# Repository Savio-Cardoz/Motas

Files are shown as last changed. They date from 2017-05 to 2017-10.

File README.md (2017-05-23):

# Motas
Code for Motas controller with Ultrasonic, PIR and sd card implemented

Functions the abstraction layer can use.

To get the Time Count of Ultrasonic Sensor
  uint16_t Get_Uss_Count();    returns an integer with time count equivalent to distance
  
  uint16_t Get_Pir_Count();    returns an integer with the current count of PIR sensor triggers
  
  void Reset_Pir_Count();
  
  void Dfplayer_Cmd(uint8_t cmd, uint16_t parameter);   Takes command with parameter value for that command
  
  ***** Pending addition of 'reading status of DF player to enter debug mode *******

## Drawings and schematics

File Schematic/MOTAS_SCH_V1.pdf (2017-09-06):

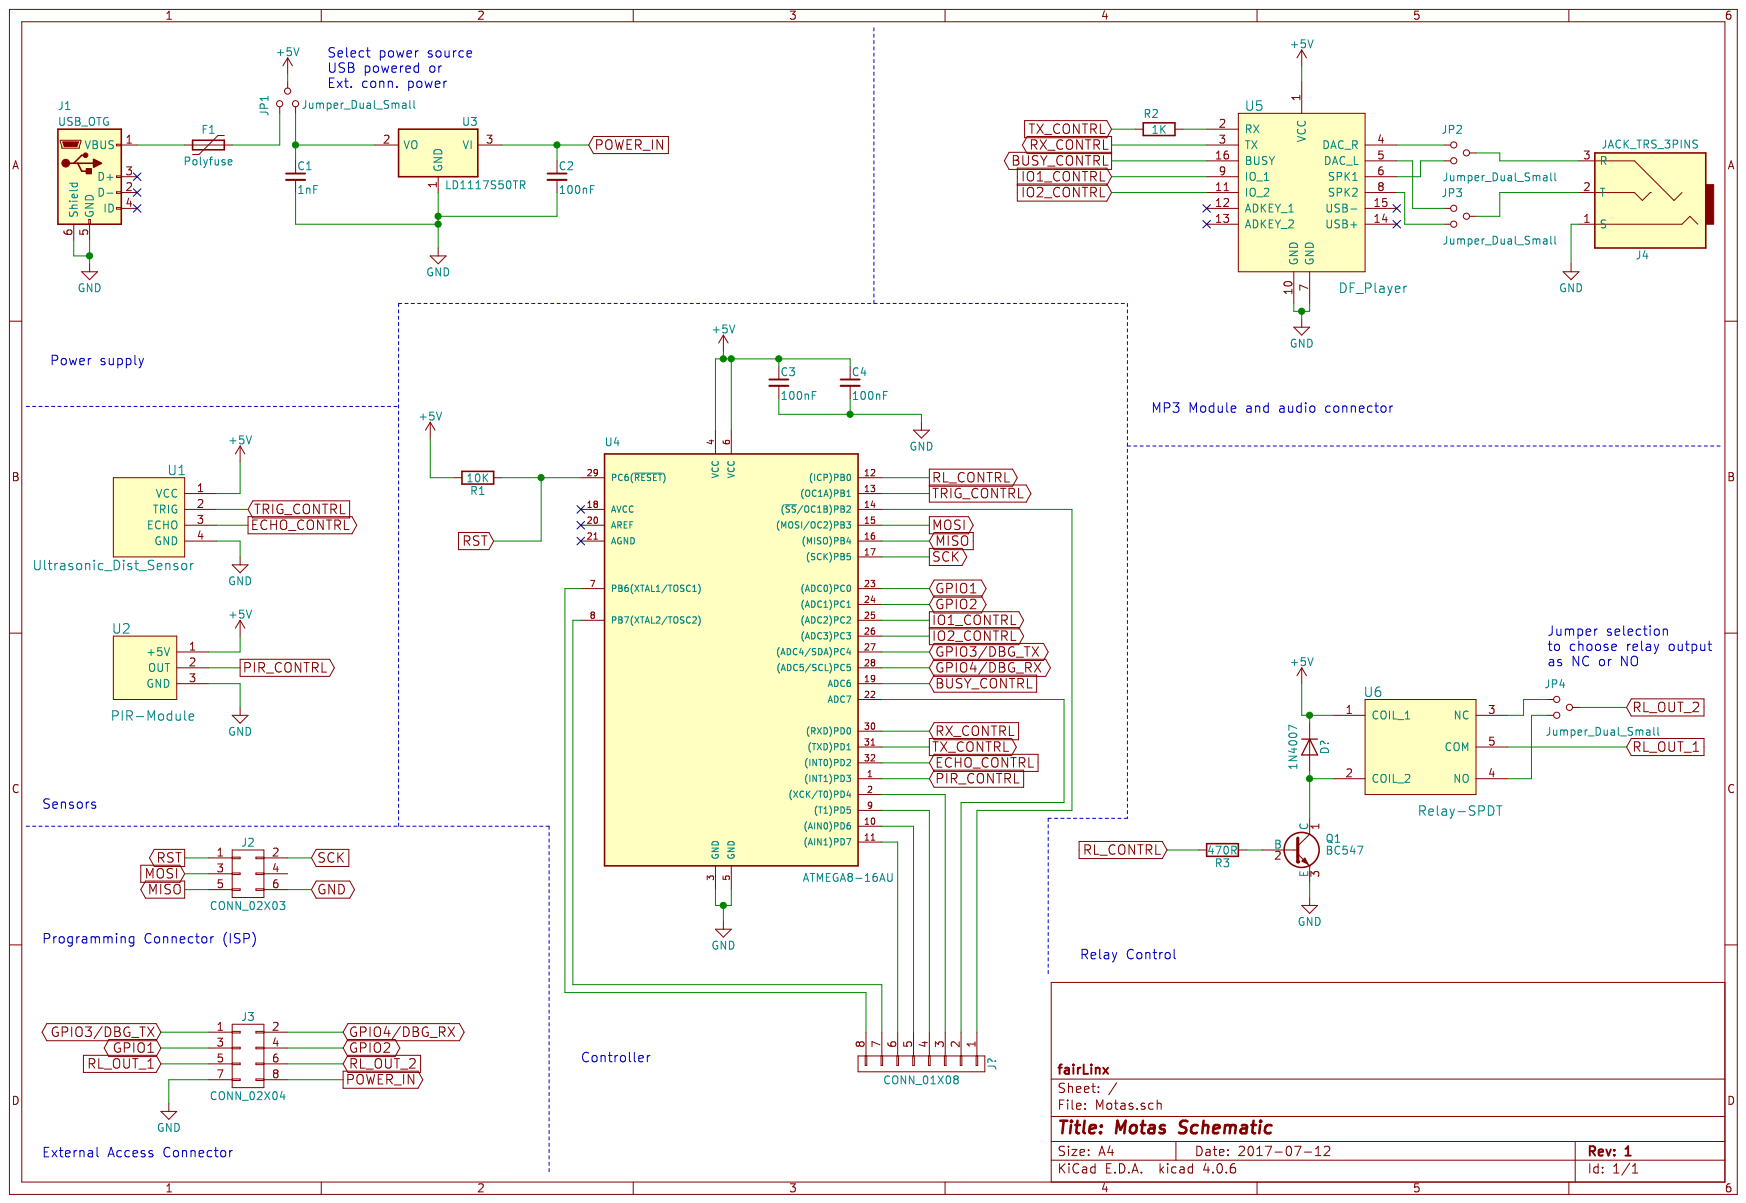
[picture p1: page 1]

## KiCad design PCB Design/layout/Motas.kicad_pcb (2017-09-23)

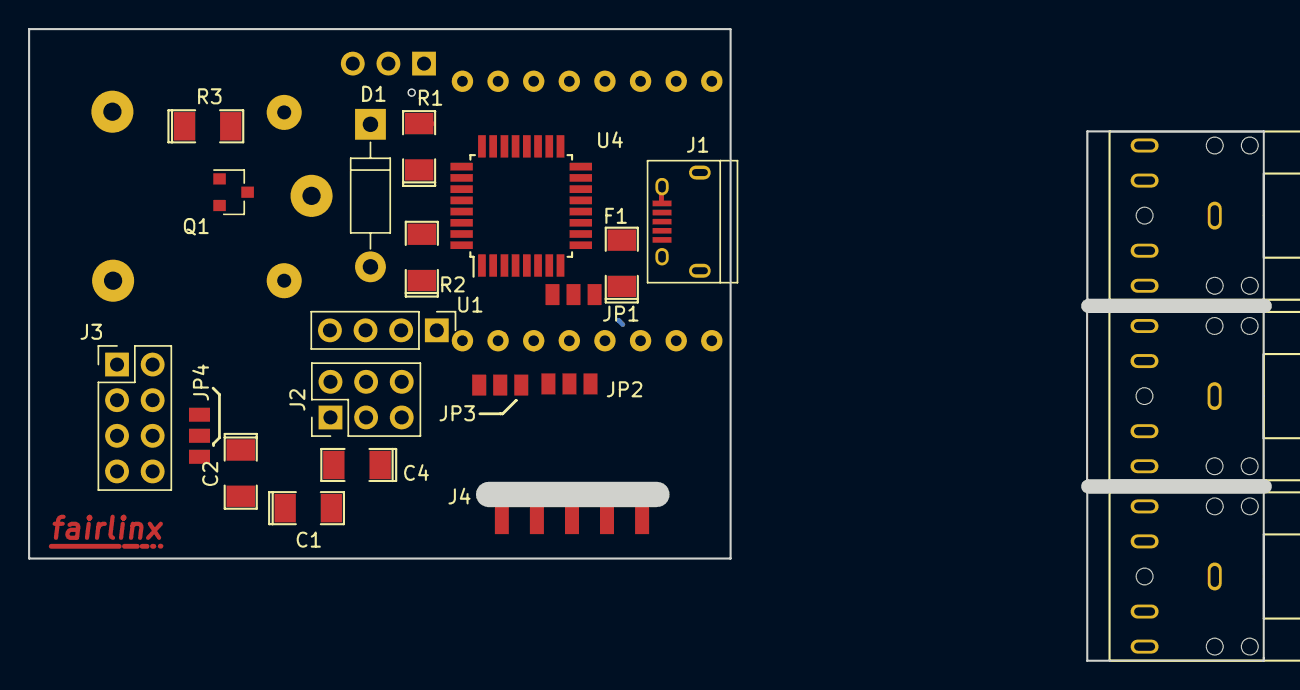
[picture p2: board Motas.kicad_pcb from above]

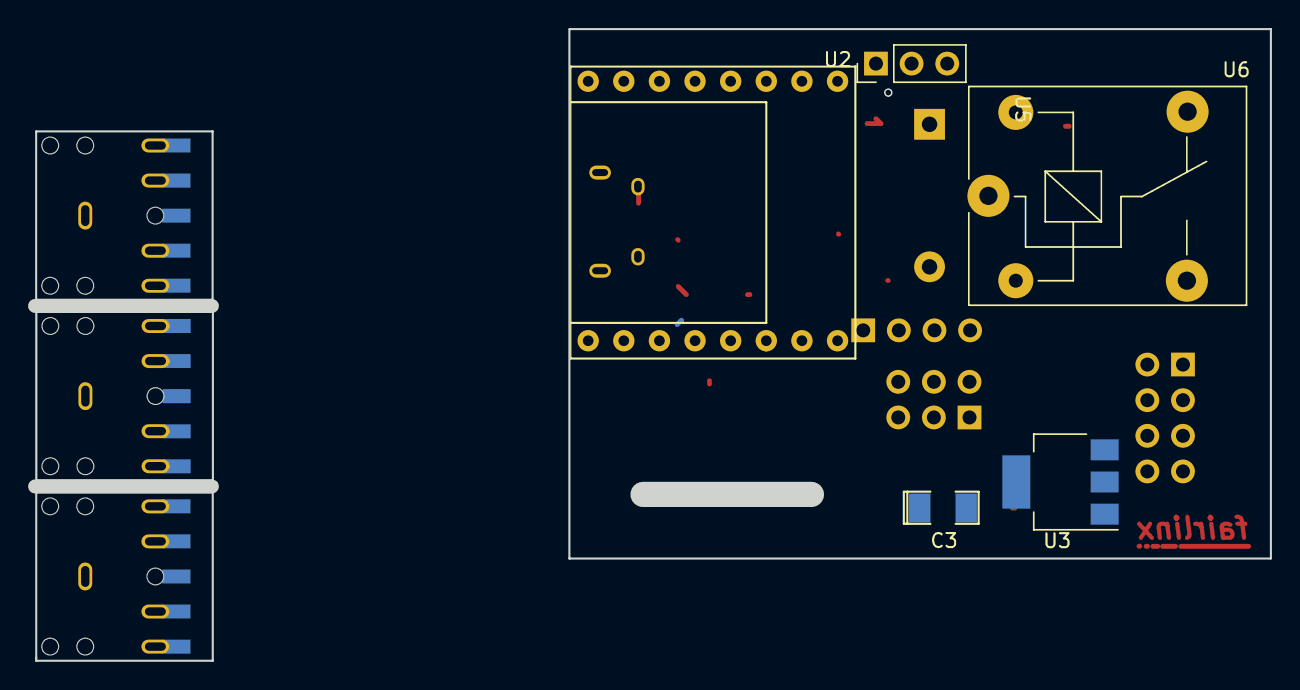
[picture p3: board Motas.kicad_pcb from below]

Board: 2 copper layers, 50.0 x 37.8 mm, 24 parts (5 on the bottom side), 36 nets.

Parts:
C1, C2, C3, C4: SMD-1206_Pol
D1: D_DO-41_SOD81_P10.16mm_Horizontal
F1: SMD-1206_Pol
J1: USB_Micro-B
J2: Pin_Header_Straight_2x03_Pitch2.54mm
J3: Pin_Header_Straight_2x04_Pitch2.54mm
J4: special_con_audio_socket_PCB
JP1, JP2, JP3, JP4: Jumper_3Pin_SMD
Q1: SOT-23
R1, R2, R3: SMD-1206_Pol
U1: Pin_Header_Straight_1x04_Pitch2.54mm
U2: Pin_Header_Straight_1x03_Pitch2.54mm
U3: SOT-223-3Lead_TabPin2
U4: TQFP-32_7x7mm_Pitch0.8mm
U5: DFPlayer
U6: Relay_SPDT_SANYOU_SRD_Series_Form_C

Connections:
+5V: C3.1, C4.1, D1.1, JP1.2, R1.2, U1.1, U2.1, U4.4, U4.6, U5.1, U6.5
BUSY_CONTRL: U4.19, U5.16
ECHO_CONTRL: U1.3, U4.32
GND: C1.2, C2.2, C3.2, C4.2, J1.5, J1.6, J2.6, J3.7, J4.1, Q1.2, U1.4, U2.3, U3.1, U4.3, U4.5, U5.7, U5.10
GPIO1: J3.3, U4.23
GPIO2: J3.4, U4.24
GPIO3/DBG_TX: J3.1, U4.27
GPIO4/DBG_RX: J3.2, U4.28
IO1_CONTRL: U4.25, U5.9
IO2_CONTRL: U4.26, U5.11
MISO: J2.5, U4.16
MOSI: J2.3, U4.15
unnamed: C1.1, JP1.3, U3.2
unnamed: D1.2, Q1.3, U6.2
unnamed: F1.1, JP1.1
unnamed: F1.2, J1.1
unnamed: J4.2, JP3.2
unnamed: J4.3, JP2.2
unnamed: JP2.1, U5.4
unnamed: JP2.3, U5.6
unnamed: JP3.1, U5.5
unnamed: JP3.3, U5.8
unnamed: JP4.1, U6.4
unnamed: JP4.3, U6.3
unnamed: Q1.1, R3.1
unnamed: R2.1, U5.2
PIR_CONTRL: U2.2, U4.1
POWER_IN: C2.1, J3.8, U3.3
RL_CONTRL: R3.2, U4.12
RL_OUT_1: J3.5, U6.1
RL_OUT_2: J3.6, JP4.2
RST: J2.1, R1.1, U4.29
RX_CONTRL: U4.30, U5.3
SCK: J2.2, U4.17
TRIG_CONTRL: U1.2, U4.13
TX_CONTRL: R2.2, U4.31

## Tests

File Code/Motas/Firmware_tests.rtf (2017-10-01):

1. Checked controller enters the main loop and loops through MotasController(); 26/09/2017
2. system state changes – POWER ON – MOTAS_INIT_STATE
void Init_State(void) → MOTAS_CALIBRATION_STATE
void Calibration_State(void) → Confusion here ???????????

3. Rectified code for swapped interrupt vectors to USS and PIR

4. Verified PIR being triggered as well as USS.
5. Systems goes through MOTAS_CALIBRATION_STATE . USS threshold set.
6. System enters MOTAS_STANDBY_STATE. USS and PIR values being monitored
7. scan rate seems to be slow. Maybe because debugging is active ____NEEDS TO BE VERIFIED

8. System enters MOTAS_ACTIVE_STATE. Cmd to play track sent.
9. USS needs to be auto triggered.

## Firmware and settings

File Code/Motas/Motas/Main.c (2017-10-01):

/*
 * MOTAS.c
 *
 * Created: 5/17/2017 10:53:48 PM
 *  Author: Cardoz
 */

 
/*
 *	Using the factory default internal RC oscillator
*/ 

#include <avr/io.h>
#include <util/delay.h>
#include <avr/interrupt.h>
#include "Atmega_Uart.h"
#include "Dfplayer.h"
#include "Peripheral_Drivers.h"
#include "Atmega_Config.h"
#include "Motas_Controller.h"
#include "debug_func.h"



int main(void)
{
	Atmega_init();
	
    while(1)
    {
		MotasController();
    }
}

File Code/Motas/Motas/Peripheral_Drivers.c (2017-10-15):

/*
 * peripheral_drivers.c
 *
 * Created: 5/17/2017 10:57:21 PM
 *  Author: Cardoz
 */ 
#include "Atmega_Config.h"
#include <avr/io.h>
#include <util/delay.h>
#include <avr/interrupt.h>
#include "Peripheral_Drivers.h"
#include "Motas_Controller.h"
#include "debug_func.h"
#include "Atmega_Uart.h"

static volatile uint16_t pir_trigger_count, UssPulseCount;
static volatile uint16_t timer1_ovf_count = 0;
extern uint8_t flag_register_controller;
extern uint16_t threshold_uss_count;

#define SET_USS_FLAG	({flag_register_controller |= (1 << 2);})
#define CLEAR_USS_FLAG  ({flag_register_controller &= ~(1 << 2);})

ISR(TIMER1_OVF_vect)
{
	++timer1_ovf_count;
}

ISR(TIMER0_OVF_vect)
{
	static uint16_t timer_ovf_count = 0;
	
	if((timer_ovf_count++) == 500)
	{
		Trigger_Ultrasonic_Sensor();
		timer_ovf_count = 0;
		TCCR0 &= ~(1 << CS00);		// Stop the timer. Timer is restarted in the USS echo received interrupt
		TCNT0 = 0;
	}
}

ISR(PIR_INTERRUPT_VECT)
{
	pir_trigger_count++;
}

ISR(USS_INTERRUPT_VECT)				
{
	static uint8_t UssEdgeCount = 0;
	if (UssEdgeCount)		
	{
		Stop_Timer1();
		UssPulseCount = TCNT1;		// Store the time duration of the echo pulse. 
		timer1_ovf_count = 0;
		TCNT1 = 0;
		UssEdgeCount = 0;
		MCUCR |= (1 << ISC01) | (1 << ISC00);												// Rising edge will trigger the next interrupt
		TCCR0 |= (1 << CS00);					// Start the timer0 to wait for 1ms to trigger the USS
		
		if(UssPulseCount < threshold_uss_count)
		{
			#if DEBUG_ON
			SendDebug("Thres_cross");
			USART_Transmit_dec(UssPulseCount);
			#endif	
			DebugLedTransmit(LED_ON, LED_RED);
			SET_USS_FLAG;	
		}
	}
	else 
	{
		Start_Timer1();
		UssEdgeCount = 1;
		MCUCR &= ~(1 << ISC00);										// falling edge for INT0 enabled
		MCUCR |= (1 << ISC01);
	}
}

void Trigger_Ultrasonic_Sensor()									// Function tested for 10us trigger 
{
	SETBIT(USS_TRIGGER_PORT, USS_TRIGGER_PIN);
	_delay_us(10);													// 10us Pulse as per datasheet of HC-SR04 Ultrasonic Sensor
	CLEARBIT(USS_TRIGGER_PORT, USS_TRIGGER_PIN);
}

void Init_Pir()
{
	CLEARBIT(PIR_INPUT_DIR_REG, PIR_INPUT_PIN);						// Set the pin direction as input
	SETBIT(PIR_INPUT_PORT, PIR_INPUT_PIN);							// Setup the controllers internal Pull up resistor

	MCUCR |= (1 << ISC11) | (1 << ISC10);
	GICR |= (1 << INT1);
}

void Init_Ultrasonic_Sensor()
{
	USS_TRIGGER_DIR_REG |= (1 << USS_TRIGGER_PIN);					// Set the pin direction as output
	USS_TRIGGER_PORT &= ~(1 << USS_TRIGGER_PIN);					// Initial state of trigger is LOW
	
	USS_ECHO_DIR_REG &= ~(1 << USS_ECHO_PIN);						// ECHO pin is set a s input
	USS_ECHO_PORT |= (1 << USS_ECHO_PIN);							// Keep ECHO pin pulled up
	
	/* Setup rising edge interrupt on the echo pin	*/	
	MCUCR |= (1 << ISC01) | (1 << ISC00);							// Set the interrupt to trigger at the rising edge.
	GICR |= (1 << INT0);
}

void Init_Led()
{
	SETBIT(DDRC, PC0);
	SETBIT(DDRC, PC1);
	CLEARBIT(PORTC, PC0);
	CLEARBIT(PORTC, PC1);	
}

void Led_On(uint8_t led_color)
{
	SETBIT(PORTC, led_color);
}

void Led_Off(uint8_t led_color)
{
	CLEARBIT(PORTC, led_color);
}

uint16_t Get_Uss_Count()
{
	// TODO: replace with a flag to check if the USS ECHO pulse has been received Speed can be 
	return UssPulseCount;
}


/* Timer 0 will be used to auto trigger the USS	@ periodic intervals	*/
void Init_Timer0()
{
	TIMSK |= (1 << TOIE0);
	TCCR0 |= (1 << CS00);		// Start the timer	default 256us overflow rate @ 1MHZ.
}

void Init_Timer1()
{
	TCNT1 = 0;
	TIMSK |= (1 << TOIE1);
}

void Start_Timer1()
{
	TCCR1B |= (1 << CS10);		// No pre-scalar
}

void Stop_Timer1()
{
	TCCR1B &= ~(1 << CS10);
}

uint16_t Get_Pir_count()
{
	#if DEBUG_ON
	SendDebug("PIR@");
	USART_Transmit_dec(pir_trigger_count);
	#endif
	return pir_trigger_count;
}

void Reset_Pir_count()
{
	pir_trigger_count = 0;
}

/*
 *	Return the digital level of the pin connected to the PIR output
 *	return 1 - if PIR is being triggered
 *	return 0 - No motion is detected by the PIR.
*/ 
uint8_t Get_Pir_status()
{
	if(CHECKBIT(PIND, PIR_INPUT_PIN))
	{
		#ifdef DEBUG_ON
		SendDebug("Motion active");
		#endif
		
		return 1;
	}
	#ifdef DEBUG_ON
	SendDebug("No Motion");
	#endif
	
	return 0;
}

void Init_Gpio()
{
	RELAY_PORT_DIR_REG |= (1 << RELAY_PIN);		// Set the relay pin as a output pin
	RELAY_PORT &= ~(1 << RELAY_PIN);			// Initialise relay in OFF state.
}

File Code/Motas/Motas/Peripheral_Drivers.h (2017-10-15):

/*
 * peripheral_drivers.h
 *
 * Created: 5/17/2017 10:56:58 PM
 *  Author: Cardoz
 */ 


#ifndef PERIPHERAL_DRIVERS_H_
#define PERIPHERAL_DRIVERS_H_
#include "Atmega_Config.h"

#define SETBIT(ADDRESS,BIT) (ADDRESS |= (1<<BIT))			
#define CLEARBIT(ADDRESS,BIT) (ADDRESS &= ~(1<<BIT))
#define CHECKBIT(ADDRESS,BIT) (ADDRESS & (1<<BIT))	

//#define PIR_INTERRUPT_VECT(number) INT##number##_vect
#define PIR_INTERRUPT_VECT 			INT1_vect						// PIR output should be input to controller on INT0
#define USS_INTERRUPT_VECT			INT0_vect
#define PIR_INPUT_PORT				PORTD
#define PIR_INPUT_DIR_REG			DDRD
#define PIR_INPUT_PIN				PIND3				

#define USS_TRIGGER_PIN				1
#define USS_TRIGGER_PORT			PORTB
#define USS_TRIGGER_DIR_REG			DDRB
#define USS_ECHO_PIN				PIND2
#define USS_ECHO_PORT				PORTD
#define USS_ECHO_DIR_REG			DDRD

#define RELAY_PIN					0
#define RELAY_PORT					PORTB
#define RELAY_PORT_DIR_REG			DDRB

#define RELAY_ON					(RELAY_PORT |= (1 << RELAY_PIN))
#define RELAY_OFF					(RELAY_PORT &= ~(1 << RELAY_PIN))

/*********************************************************************************************************************
*					Local variables
********************************************************************************************************************/


/**********************************************************************************************************************
*					Function Prototypes
*********************************************************************************************************************/
void Trigger_Ultrasonic_Sensor();
void Init_Pir();
void Init_Ultrasonic_Sensor();
uint16_t Get_Uss_Count();
uint16_t Get_Pir_count();
void Reset_Pir_count();
uint8_t Get_Pir_status();
void Led_On(uint8_t led_color);
void Led_Off(uint8_t led_color);
void Init_Gpio();
void Stop_Timer1();
void Start_Timer1();
void Init_Timer1();
void Init_Timer0();

#endif /* PERIPHERAL_DRIVERS_H_ */

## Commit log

2017-05-19 Added schematic and schematic library files
    [MOTAS_HW.PrjPcb, MOTAS_sch.SchDoc, Schlib1.SchLib]
2017-05-31 sd card and led not implemented. Doxugen format implemented for changed files.Check for compilation issues.
2017-06-04 Updated funtions
    Added function -> Get_Pir_Status, which will return the Status of motion as 1 or 0.
    Added function -> Led_On(led_color) and Led_Off(led_color).
    Modified SendDebug()
    Tested funtioning of the PIR motion, USS distance count, mp3 player command and LED control.
2017-06-22 Adding the latest 3D files
    [MOTAS_3D_PRINT_190617.stl, out.obj]
2017-07-08 Enclosure model revision. Ports at the back
    [MOTAS_3D_PRINT_030717.stl]
2017-09-06 Files reorganised
    [3D_design_MOTAS.skp, MOTAS SIM.DSN, MOTAS_3D_PRINT_030717.stl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]
2017-09-23 added software uart
    [Motas.kicad_pcb]
2017-09-23 Can debug using LED indications
2017-09-30 resolved problem of no USS and PIR counts. Interrupts were were wrongly assigned
    [Main.c, Peripheral_Drivers.c, Peripheral_Drivers.h]
2017-10-04 Debugging Active state failure
    [Peripheral_Drivers.c]
